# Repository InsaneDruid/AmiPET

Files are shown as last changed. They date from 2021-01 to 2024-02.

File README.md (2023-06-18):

# AmiPET
A simple Arduino Shield which offers the possibility to use Amiga keyboards on Commodore PET computers.
It uses the Arduino to communicate with an Amiga keyboard and control a M3493B2 Crosspoint to switch the PET keyboard matrix.

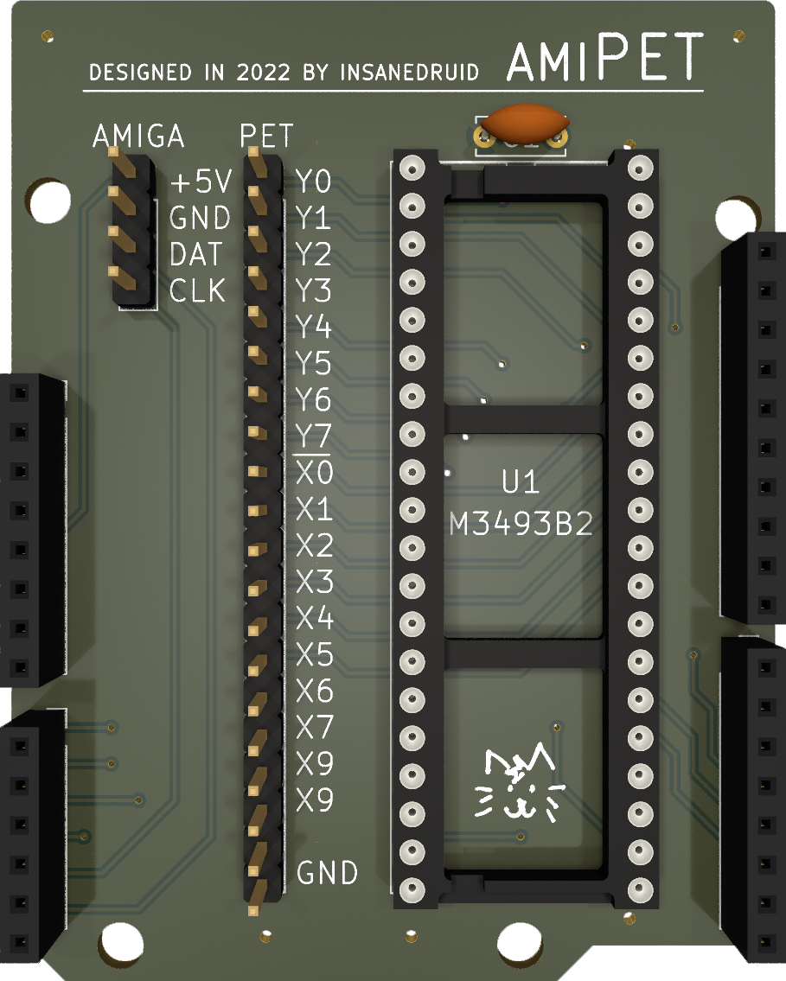
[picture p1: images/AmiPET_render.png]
AmiPET render


[Schematic](https://github.com/InsaneDruid/AmiPET/blob/main/AmiPET.pdf "Schematic")  

[Bill of Materials](https://htmlpreview.github.io/?https://github.com/InsaneDruid/AmiPET/blob/main/bom/AmiPET_bom.html "Bill of Materials")

## Background
Amiga side sends *rawkey* codes to the Arduino. An array of tupels contains bitvalues for the M3493B2 to switch the PET keyboard matrix rows and columns to the appropriate key. Entries represent Amiga rawkey codes #00 to #68 (0-103 decimal).

The sketch uses Arduino port bitwise operations to keep the latency low. Row values are encoded by bitvalues of 1 2 4 6 on bits 0-3 (logic hole in M3493B2), bits 4-6 are unused , bit 7 marks undefined keys (no PET key will be sent).
Colum bits are leftshifted 2 bits to accomodate Arduino port setup (PD0, PD1 left free for serial communication) and encode bitvalues of 1 2 4 on bits 2-4. Bit 0,1,5,6 are unused, Bit7 of marks shifted keys (cursor left/up). On those the arduino will send a Shift key press/release before sending the encoded key to the PET.

## How to change the Key Bindings
+ Get desired PET matrix entry and Amiga rawkey code.
+ Edit the (n+1)th tupel of *key_matrix* in *Amiga_PETkey.h* where n = amiga rawkey code.
+ Encode PET Row Number with bitvalues of 1 2 4 6 for bits 0-3. Set bit 7 if no PET key should be generated for this amiga key.
+ Encode PET Column Number with bitvalues 1 2 4 for bits 2-4. Set bit 7 if key should be shifted on PET side.

### Example1
Amiga *6* to PET *6*

+ Rawkey code of Amiga *6* key is #06 = 6 decimal, so edit the 7th tupel in the key_matrix array.
+ The keyboard scan matrix for the *6* key on a UK PET Business keyboard is *Row 9 Colum 2*
+ As the M2493B2 interprets the 4th row bit as 6 instead of 8, the row entry is 0b00001011.
+ Column entry is 2bit leftshifted binary representation of decimal 2.

Result: {0b00001011, 0b00001000}

### Example2
Amiga *Cursor Up* to PET *Shift+Cursor Up/Down*

+ Rawkey code of *Amiga Cursor Up* key () is #4C = 76 decimal, so edit the 77th tupel in the key_matrix array.
+ The keyboard scan matrix for the *Cursor Up/Down* key on a UK PET Business keyboard is *Row 5 Colum 4*.
+ The Row entry is a straigt binary representation of decimal 5.
+ Column entry is 2bit leftshifted binary representation of decimal 4 with bit 7 set addintionally to press/release shift before the *Cursor Up/Down* key on the PET side.

Result: {0b00000101, 0b10010000}

## Connecting the Adapter
+ The PET can supply unregulated 9VDC via the internal *RAWPwr" Headers (J11 on a universal Board) to both the Arduinos *VIN* pin and the M3493B2.
+ The Amiga keyboard needs +5V and GND from the Arduino as well as a connection to KBCLK (Arduino PC4) and KBData (Arduino PC5)
+ The PET keyboard connector gets connected to the X0-X9 pins (rows) and the Y0-Y7 pins (colums) of the M3493B2 as well as Ground.

## Printable Parts

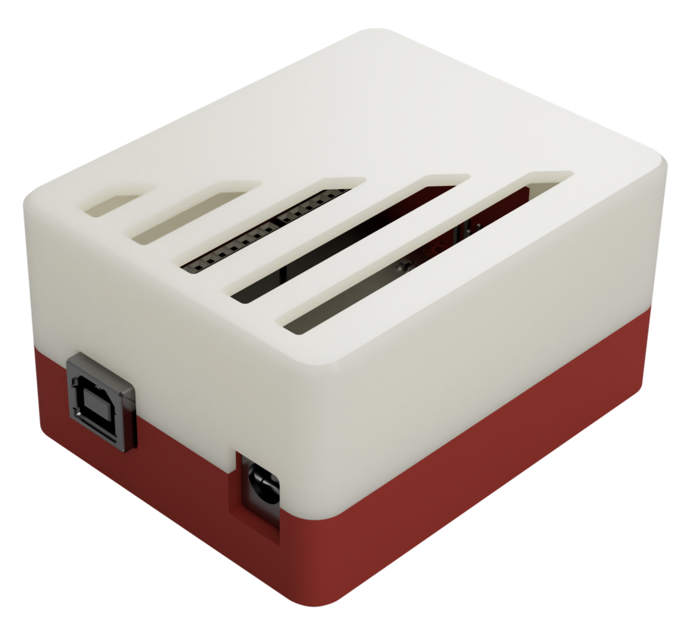
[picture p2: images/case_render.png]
3D printable case render


+ *DIN_Connector_Mount .stl* can be used to mount the DIN Connector in place of the keyboard connector of an 8032-SK/8296.
+ *Case_Top.stl* and *Case_Bottom.stl* are designed to fit an Uno with the M3493B2 shield mounted.

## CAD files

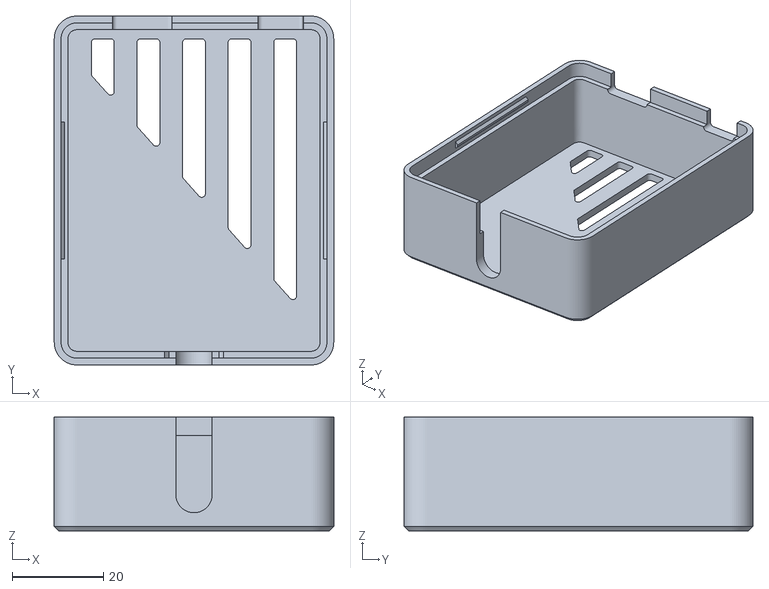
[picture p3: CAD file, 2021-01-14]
Printable Parts/Case_Top.stl
61.3 x 76.6 x 25.0

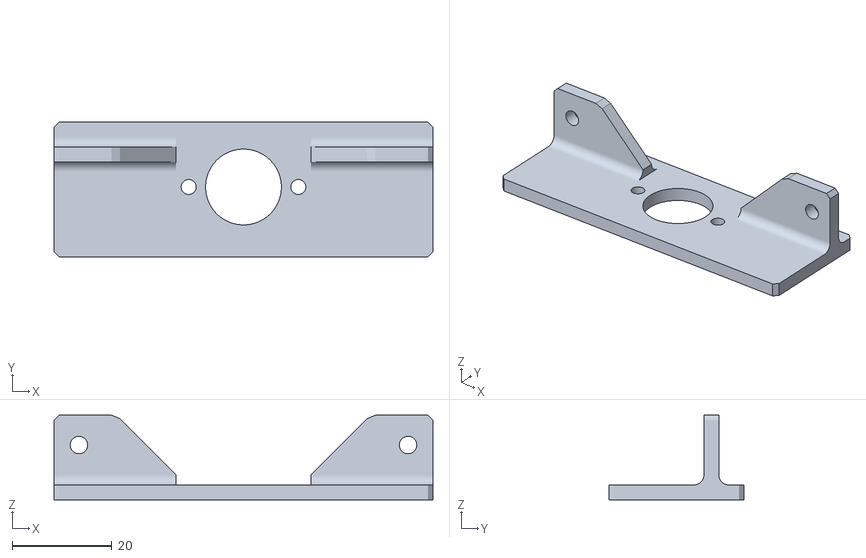
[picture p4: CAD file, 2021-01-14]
Printable Parts/DIN_Connector_Mount .stl
76.0 x 27.0 x 17.0

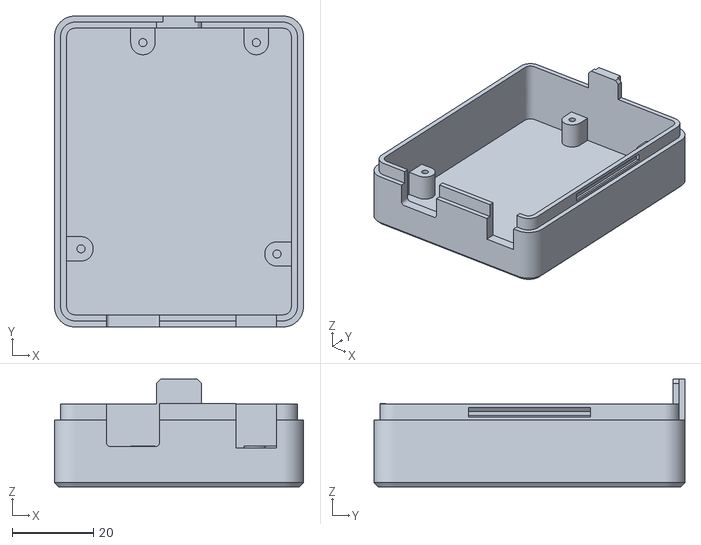
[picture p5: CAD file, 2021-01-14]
Printable Parts/Case_Bottom.stl
61.3 x 76.6 x 26.5

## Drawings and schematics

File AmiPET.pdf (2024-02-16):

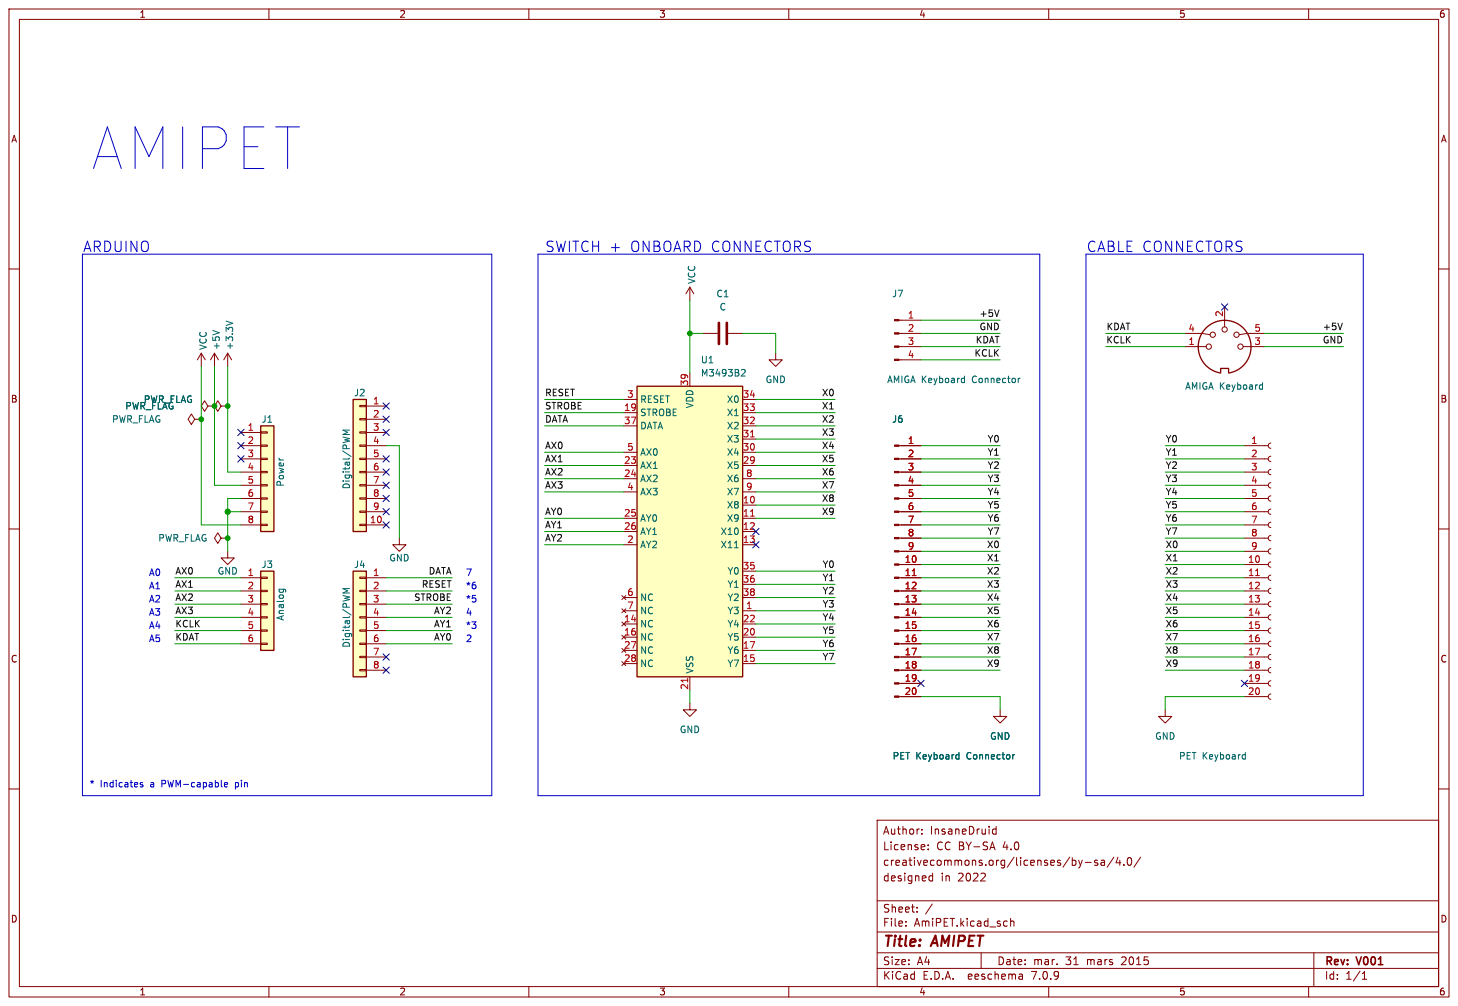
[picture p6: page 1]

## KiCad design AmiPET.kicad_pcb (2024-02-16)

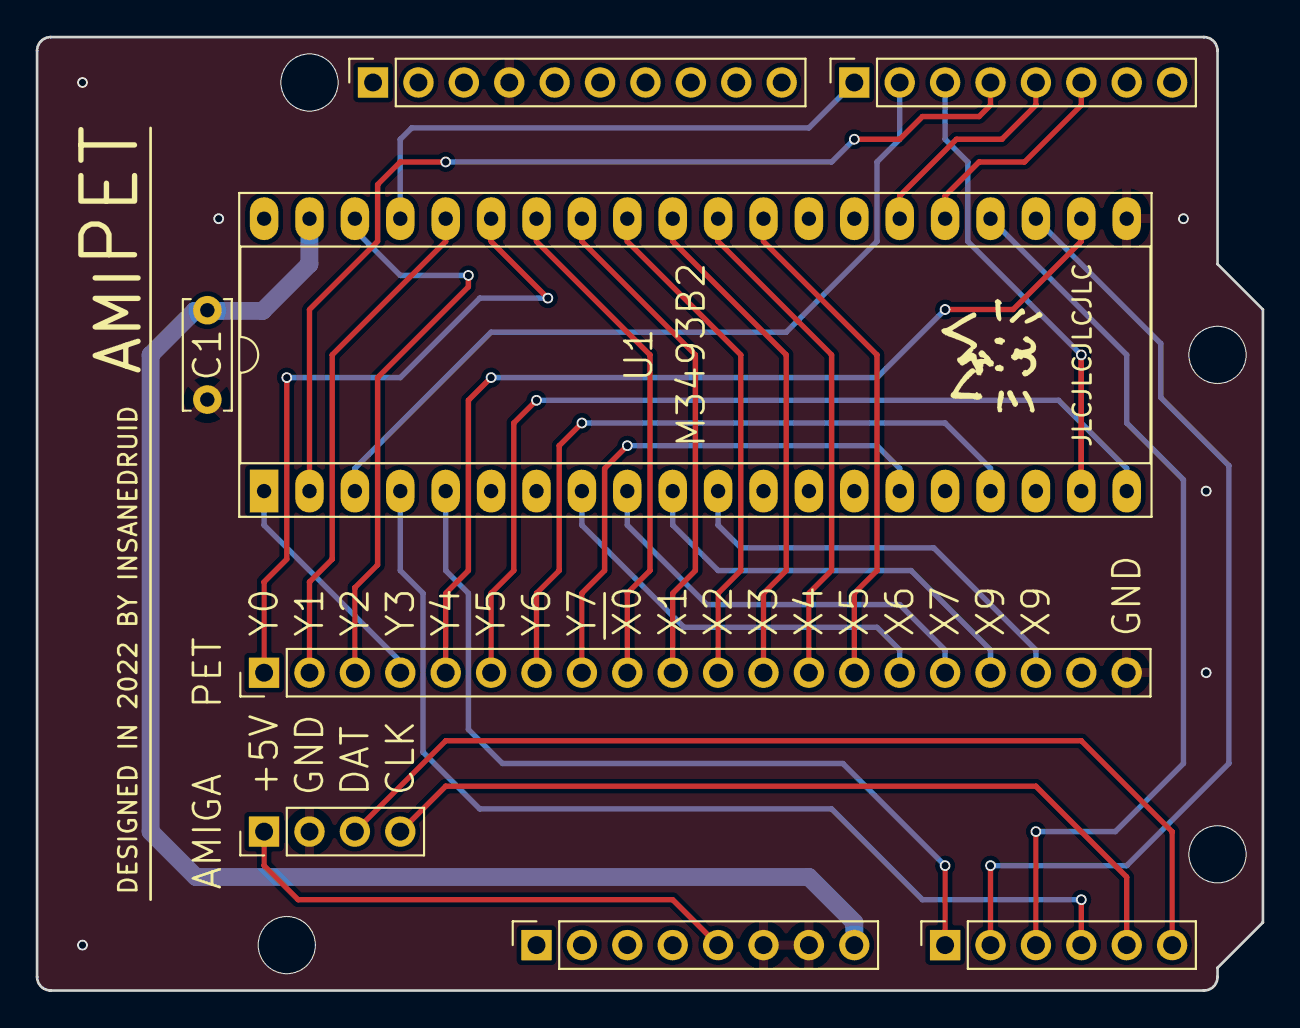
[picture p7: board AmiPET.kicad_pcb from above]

Board: 2 copper layers, 68.6 x 53.3 mm, 12 parts (0 on the bottom side), 33 nets.

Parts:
C1: C; C_Disc_D6.0mm_W2.5mm_P5.00mm
J1: Power; PinSocket_1x08_P2.54mm_Vertical
J2: Digital/PWM; PinSocket_1x10_P2.54mm_Vertical
J3: Analog; PinSocket_1x06_P2.54mm_Vertical
J4: Digital/PWM; PinSocket_1x08_P2.54mm_Vertical
J6: PET Keyboard Connector; PinHeader_1x20_P2.54mm_Vertical
J7: AMIGA Keyboard Connector; PinHeader_1x04_P2.54mm_Vertical
MH1, MH2, MH3, MH4: MountingHole_3.2mm
U1: M3493B2; DIP-40_W15.24mm_Socket_LongPads

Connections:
+5V: J1.5, J7.1
/AX0: J3.1, U1.5 (AX0)
/AX1: J3.2, U1.23 (AX1)
/AX2: J3.3, U1.24 (AX2)
/AX3: J3.4, U1.4 (AX3)
/AY0: J4.6, U1.25 (AY0)
/AY1: J4.5, U1.26 (AY1)
/AY2: J4.4, U1.2 (AY2)
/DATA: J4.1, U1.37 (DATA)
/KCLK: J3.5, J7.4
/KDAT: J3.6, J7.3
/RESET: J4.2, U1.3 (RESET)
/STROBE: J4.3, U1.19 (STROBE)
/X0: J6.9, U1.34 (X0)
/X1: J6.10, U1.33 (X1)
/X2: J6.11, U1.32 (X2)
/X3: J6.12, U1.31 (X3)
/X4: J6.13, U1.30 (X4)
/X5: J6.14, U1.29 (X5)
/X6: J6.15, U1.8 (X6)
/X7: J6.16, U1.9 (X7)
/X8: J6.17, U1.10 (X8)
/X9: J6.18, U1.11 (X9)
/Y0: J6.1, U1.35 (Y0)
/Y1: J6.2, U1.36 (Y1)
/Y2: J6.3, U1.38 (Y2)
/Y3: J6.4, U1.1 (Y3)
/Y4: J6.5, U1.22 (Y4)
/Y5: J6.6, U1.20 (Y5)
/Y6: J6.7, U1.17 (Y6)
/Y7: J6.8, U1.15 (Y7)
GND: C1.2, J1.6, J1.7, J2.4, J6.20, J7.2, U1.21 (VSS)
VCC: C1.1, J1.8, U1.39 (VDD)

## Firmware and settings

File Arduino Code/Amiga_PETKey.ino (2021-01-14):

/*
  AmiPET - Use an Amiga Keyboard on a Commodore PET
  The Amiga Keyboard to Arduino communication is based on Code from Olaf Berthold https://forum.arduino.cc/index.php?topic=139358.0
*/

#include "Amiga_PETKey.h"

void setup() {
  DDRC &= ~(BITMASK_A500CLK | BITMASK_A500DAT);                           // INPUT
  DDRC |= BITMASK_SWITCH_ROW;                                             // OUTPUT
  DDRD |= BITMASK_SWITCH_COL;                                             // OUTPUT
  DDRD |= (BITMASK_SWITCH_STB | BITMASK_SWITCH_DAT | BITMASK_SWITCH_RST); // OUTPUT

  switchReset();
  state = SYNC;
}

void loop() {
  if (state == SYNC) {                                                    // sync pulse LOW
    if ((PINC & BITMASK_A500CLK) != 0) state = HANDSHAKE;
  }
  else if (state == HANDSHAKE) {                                          // handshake
    if (counter == 0) {
      DDRC |= BITMASK_A500DAT;                                            // set IO direction to OUTPUT
      PORTB &= ~BITMASK_A500DAT;                                          // set OUTPUT to LOW
      counter = millis();
    }
    else if (millis() - counter > 10) {
      counter = 0;
      DDRC &= ~BITMASK_A500DAT;                                           // set IO direction to INPUT
      state = WAIT_LO;
      key = 0;
      bitn = 7;
    }
  }
  else if (state == WAIT_LO) {                                            // waiting for the next bit
    if ((PINC & BITMASK_A500CLK) == 0) {
      noInterrupts();
      state = READ;
    }
  }
  else if (state == READ) {                                               // read key message (8 bits)
    if ((PINC & BITMASK_A500CLK) != 0) {
      if (bitn--) {
        key += ((PINC & BITMASK_A500DAT) == 0) << (bitn);                 // key code (add bits 0...6)
        state = WAIT_LO;
      }
      else {                                                              // read last bit (key down)
        keydown = ((PINC & BITMASK_A500DAT) != 0);                        // true if key down
        interrupts();
        state = HANDSHAKE;
        if (!(key_matrix[key][0] & 0b10000000)) {                         // key has existing PET definition
          if (keydown) {
            if (key_matrix[key][1] & 0b10000000) {                        // key matrix entry needs PET shift key to be pressed
              shiftPress();
            }
            switchSetPressed();
          }
          else {
            if (key_matrix[key][1] & 0b10000000) {                        // key matrix entry needs PET shift key to be released
              shiftRelease();
            }
            switchSetReleased();
          }
          switchSetKey(key);
          switchStrobe();
        }
      }
    }
  }
}

void switchSetKey(uint8_t k) {
  PORTC &= ~BITMASK_SWITCH_ROW;                                         // ROWS: clear all bits in row mask area
  PORTC |= (BITMASK_SWITCH_ROW & key_matrix[k][0]);                     // ROWS: set Bits in row mask Area according to Keyboard key_matrix

  PORTD &= ~BITMASK_SWITCH_COL;                                         // COLUMS: clear all bit in colum mask area
  PORTD |= (BITMASK_SWITCH_COL & key_matrix[k][1]);                     // COLUMS: set bits in column mask area according to Keyboard key_matrix
}

void switchSetPressed() {
  PORTD |= BITMASK_SWITCH_DAT;
}

void switchSetReleased() {
  PORTD &= ~BITMASK_SWITCH_DAT;
}

void switchStrobe() {                                                   // activate switches according to state of select lines
  PORTD |= BITMASK_SWITCH_STB;
  PORTD &= ~BITMASK_SWITCH_STB;
}

void shiftPress() {
  switchSetKey(0x60);
  switchSetPressed();
  switchStrobe();
}

void shiftRelease() {
  switchSetKey(0x60);
  switchSetReleased();
  switchStrobe();
}

void switchReset() {
  PORTD |= BITMASK_SWITCH_RST;
  delay(1);
  PORTD &= ~BITMASK_SWITCH_RST;
}

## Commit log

2021-01-14 Updated Content
    [Case_Bottom.stl, Case_Top.stl, DIN_Connector_Mount .stl]
2022-12-09 PCB Project added
    [AmiPET.kicad_pcb, AmiPET.kicad_sch]
2023-06-18 PCB Project update
    tweaked layout
    new 3d models
    added schematic, production files, bom and image
    removed old painted schematic
    [AmiPET.kicad_pcb, AmiPET.kicad_sch]
2023-06-18 case render
2024-02-16 added jlc order number markers
    added jlc order number position marker to pcb
    fixed licence links in drawing sheets to match board prints, readme and project
    added desktop ini to gitignore
    [AmiPET.kicad_pcb, AmiPET.kicad_sch]

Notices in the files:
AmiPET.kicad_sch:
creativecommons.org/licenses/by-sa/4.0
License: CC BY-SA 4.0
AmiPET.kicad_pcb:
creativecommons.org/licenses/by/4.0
